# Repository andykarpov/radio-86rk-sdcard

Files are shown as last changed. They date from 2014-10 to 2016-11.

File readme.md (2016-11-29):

# Адаптер SD-CARD для Радио-86РК_SRAM

Данный проект является развитием проекта адаптера SD-CARD  от **Vinxru** 

## Изменения в схеме и печатной плате
- Добавлен LDO регулятор LM1117 3v3
- Вместо резистивных делителей используется буфер HEF4050BT
- добавлен 26-контактный IDC разъем под кабель для сопряжения модуля с Радио-86РК_SRAM
- Добавлен 6-контактный разъем для программатора
- Вместо Atmega8L используется МК Atmega328P

Плата разработана в CAD Eagle 7.0 и выполнена в форм-факторе 5x5 см, что дает возможность заказать ее производство у китайцев. Пробная первая партия была заказана у [http://www.dfrobot.com](http://www.dfrobot.com).

Gerber-файлы для производства платы проходят валидацию по стандартам pcb-сервиса от dfrobot.com.

## Фото готового устройства

Фото

## BOM-list

Микросхемы:

- U1 - Atmega8L(A) (или Atmega328P, или аналогичный МК)

- U2 - HEF4050BT (или другого производителя, 4050 в SMD-корпусе)

- IC1 - LM1117-3.3V

Разъемы:

- CONN1 - 4UCon 19646 или аналогичный ([pdf](http://www.4uconnector.com/online/object/4udrawing/19608.pdf), [Sparkfun](https://www.sparkfun.com/products/12769), [noname разъем на ebay](http://www.ebay.com/itm/5-Pcs-SD-Memory-Card-Sockets-Connectors-Replacements-29-x-28-5-x-2-5mm-/291005194440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))

- CONN2 - угловой 2x13-контактный IDC-разъем (шаг 2.54мм)

- CONN3 - вертикальный 2x3-контактный pin header (шаг 2.54мм)

Резисторы:

- R1 - 470 Ом, корпус 1206

Конденсаторы:

- C1, C2 - 10 мкФ, танталовые полярные, корпус 1206

- C3, C4 - 0.1 мкФ, керамические, корпус 1206

Светодиод:

- LED1 - цвет свечения какой нравится, корпус 1206

## Адаптация исходного кода

Автор оригинальной разработки подготовил файлы boot.rk, sdbios.rk и shell.rk для Радио-86РК (меняются, как минимум, адреса портов).

Прошивка микроконтроллера Atmega8L остается без изменений, можно спокойно заливать авторскую.

Если же проект собирается на базе Atmega328P, то за основу можно взять модифицированную по этот камень прошивку из данного репозитария, в директории *firmware/src/atmega328p*. Вся соль не только в изменившихся адресах портов этого камня, а также в смещении переменной rom, которая в оригинальной конфигурации сидела по адресу 0100h, а теперь сидит по адресу 0200h. 

Также оказалось, что коммандер **shell.rk** не совсем корректно работает с *адаптером PS/2 клавиатуры* и моей кривой клавиатурой с неполной поддержкой ScanCode Set 3, при вызове функции биоса **getch()** возвращает странные значения для кнопок курсора. Соответственно, пришлось придумать альтернативное решение управления курсором, а именно: клавиши **Q,A,O,P**. Модифицированная версия shell.rk расположена в директории *firmware/src/shell_rk/*.

### Fuse bits для МК

На сайте [http://www.engbedded.com/fusecalc/](http://www.engbedded.com/fusecalc/) можно посчитать fuse bits для Вашего МК. 
Необходимо выбрать 

- Internal RC OSC 8MHz, 
- убрать галочку Divide clock by 8 internally

Все остальное можно не трогать или по желанию (например параметры brown out detection).

## Полезные ссылки
- Обсуждение проекта на zx-pk.ru: [http://zx-pk.ru/showthread.php?t=24092](http://zx-pk.ru/showthread.php?t=24092)

- Тема в барахолке на zx-pk.ru: [http://zx-pk.ru/market/viewtopic.php?f=7&t=2567&p=24381](http://zx-pk.ru/market/viewtopic.php?f=7&t=2567&p=24381)

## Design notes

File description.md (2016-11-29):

# Описание работы проекта 86RKSD от автора - Алексея Морозова (по материалам статей в vk.com)

Этот проект очень давно начат и много раз забрасывался. И я возвращаюсь очередной раз. Мы будем подключать флешку к компьютеру Радио 86РК, а точнее подключать к компьютеру микроконтроллер ATMega8 к которому подключена флешка.

### Зачем микроконтроллер? 

Почему бы просто карту памяти не подключить? А вот зачем:

Где то надо хранить программу, которая будет работать с картой памяти. Программа прошитая в ПЗУ компьютера умеет загружать программы только с магнитофона или ПЗУ подключенного к параллельному порту.

Микроконтроллер будет эмулировать внешнее ПЗУ. После включения компьютера, микроконтроллер читает с карты памяти файл и притворяется ПЗУ содержащим эти данные. Компьютер копирует эти данные в память и запускает.

Это только первый этап работы. Дальше пользователь должен увидеть список файлов на экране и иметь возможность как минимум запустить нужный файл. Это уже не эмуляция ПЗУ, это весьма сложная программа, которую раньше называли - дисковая операционная система.

Эта система заняла бы половину памяти компьютера, это бы не позволило запустить большинство программ. И система бы работала бы очень медленно. И сбой компьютера мог бы привести к уничтожению данных на флешке.

Поэтому я решил разместить операционную систему в микроконтроллере. Это быстрее, надежнее и это экономит ресурсы компьютера.

У микроконтроллера **ATMega8** всего **1 Кб ОЗУ** и **8 Кб ПЗУ**. Мне пришлось сильно напрячь голову, что бы написать ОС способную работать на таких скромных объемах.

### Плата

Обобщая написанное. Плата подключается к параллельному порту компьютера. На плате находится микроконтроллер, внутри которого находится эмулятор ПЗУ. Загрузить программу из ПЗУ можно с помощью стандартной директивы **R0,100 G**. Загруженная программа уже будет работать с операционной системой внутри микроконтроллера.

Помимо микроконтроллера и слота для карты, на плате еще несколько деталей для согласования карты с компьютером. Компьютер работает с напряжением **5 Вольт**, а карта памяти **3.3 Вольта**.

### Программа эмуляции ПЗУ

Писать пришлось на ассемблере, так как программа на **Си** не успевала. Компилятор **CodeVision AVR** находится в режиме оптимизации размера в ущерб скорости. Если выключить этот режим, то программа не помещается в микроконтроллер.

Ничего сложного, но заставить все это работать вместе оказалось не так просто (не так быстро). Начинаем писать:

```
// Шина данных на выход

#define DATA_OUT DDRC = 0b00111111, DDRB = 0b11101101;

// Шина данных на вход

#define DATA_IN DDRD = 0x00000000, DDRB = 0b00101101;

void main() {

  DDRD = 0;    // Шина адреса на вход

  DATA_OUT // Шина данных на выход. а так же настраиваем остальные выводы.

  PORTB = 0b00010000; // Подтягивающий резистор на MISO

  // Пауза, пока не стабилизируется питание

  delay_ms(100);

  // Запуск файловой системы

  if(fs_init()) error();

  // Открываем файл boot/boot.rk

  strcpyf(buf, "boot/boot.rk");

  if(fs_open()) error();

  // Он должен быть не больше 128 байт

  if(fs_getfilesize()) error();

  if(fs_tmp > 128) error();

  // Чиатем его в массив rom

  if(fs_read0(rom, (WORD)fs_tmp)) error();

    // Эмуляция ПЗУ

  while(1) {

#asm

        IN   R30, PIND          ; Получаем адрес от компьютера в R30

        LDI  R31, 1               ; Массив rom находится по адресу 0x100. Записываем в R31 единицу.

        LD   R30, Z               ; Читаем в R30 из адреса R31:R30

        OUT  PORTC, R30         ; Отдаем младшие 6 бит компьютеру

        IN   R31, PORTB         ; Отдаем старшие 2 бита компьютеру

        ANDI R31, 0x3F

        ANDI R30, 0xC0

        OR   R31, R30

        OUT  PORTB, R31

#endasm

  }

}
```

###Переключение из режима эмуляции ПЗУ в режим общения с микроконтроллером

Следующим этапом будет переключение из режима эмуляции ПЗУ в режим полноценного общения с микроконтроллером.

Для выхода из этого режима надо последовательно прочитать ячейки ПЗУ: **19, 23, 87**. После этого на шине данных должен появится байт **40h** (константа **ERR_START**).

1). ПРОЧИТАТЬ ДАННЫЕ ПО **АДРЕСУ 19**

2). ПРОЧИТАТЬ ДАННЫЕ ПО **АДРЕСУ 23**

3). ПРОЧИТАТЬ ДАННЫЕ ПО **АДРЕСУ 87**

Далее микроконтроллер будет отдавать данные по тактовому импульсу. В качестве тактового импульса используется линия адреса **A0**. Что бы прочитать или передать очередной байт, надо обратится по адресам **86, 87**. Чтение любого другого адреса вызовет перезагрузку контроллера и возврат в режим **эмуляции ПЗУ**.

После **ERR_START (40h)**, микроконтроллер передает байт **ERR_OK_WAIT (41h)**. И будет передавать его, пока проверяет наличие карты памяти и инициализирует файловую систему. Если инициализация прошла без ошибок, микроконтроллер передает байт **ERR_OK_DISK (42h)**.

4). ЕСЛИ ПРОЧИТАННЫЕ ДАННЫЕ **40h**, РАБОТАЕМ ДАЛЬШЕ

5). ПРОЧИТАТЬ ДАННЫЕ ПО АДРЕСУ **86**

6). ПРОЧИТАТЬ ДАННЫЕ ПО АДРЕСУ **87**

7). ЕСЛИ ПРОЧИТАННЫЕ ДАННЫЕ **41h**, ПЕРЕЙТИ НА ПУНКТ 5

8). ЕСЛИ ПРОЧИТАННЫЕ ДАННЫЕ **42h**, РАБОТАЕМ ДАЛЬШЕ

Дальше, компьютер должен переключить шину данных на передачу, а микроконтроллер на прием. Если компьютер и контроллер одновременно переключатся в режим передачи, произойдет короткое замыкание. Что бы такого не было, переключение в режим передачи происходит в два такта.

Сначала компьютер дергает тактовый сигнал. Микроконтроллер переключается в режим приема. В этот момент времени на шине нет передающего устройства и соответственно в этот такт данные не передаются. Потом компьютер переключается в режим передачи и выставляет передаваемые данные на шину. И только после этого дергает тактовый сигнал и микроконтроллер читает данные.

9). ПРОЧИТАТЬ ДАННЫЕ ПО АДРЕСУ **86**

10). ПРОЧИТАТЬ ДАННЫЕ ПО АДРЕСУ **87**

11). ПЕРЕКЛЮЧИТЬ КОМПЬЮТЕР В РЕЖИМ ПЕРЕДАЧИ

Сейчас мы передаем все данные для команды. Код команды и её аргументы. После передачи каждого байта мы дергаем тактовую линию.

12). ПЕРЕДАТЬ БАЙТ **0** (это команда загрузки файла **sdbios.rk**)

13). ПРОЧИТАТЬ ДАННЫЕ ПО АДРЕСУ **86**

14). ПРОЧИТАТЬ ДАННЫЕ ПО АДРЕСУ **87**

После передачи команды надо опять поменять направление передачи. Микроконтроллер сохраняет данные сразу же по перепаду тактового импульса. Микроконтроллер быстрее компьютера в 20 раз. Поэтому мы можем сразу же после передачи байта переключить компьютер в режим приема. И дернуть тактовый импульс, микроконтроллер переключит шину в режим передачи и выставит передаваемый байт.

15). ПЕРЕКЛЮЧИТЬ КОМПЬЮТЕР В РЕЖИМ ПРИЕМА

16). ПРОЧИТАТЬ ДАННЫЕ ПО АДРЕСУ **86**

17). ПРОЧИТАТЬ ДАННЫЕ ПО АДРЕСУ **87**

18). ЕСЛИ ПРОЧИТАННЫЕ ДАННЫЕ **41h**, ПЕРЕЙТИ НА ПУНКТ 16

19). ЕСЛИ ПРОЧИТАННЫЕ ДАННЫЕ **47h**, РАБОТАЕМ ДАЛЬШЕ

20). ПРИНИМАЕМ И ЗАПУСКАЕМ ФАЙЛ

**Код 47** значит, что файл найден и загружен. Можно начать его прием.

Теперь надо заставить это работать.

Написал программу. Проблема была только с тем, что при переключении режима порта (прием/передача), все линии порта сбрасываются в ноль. Пришлось для тактового сигнала выбрать значения 0 и 1. И волшебная комбинация перехода стала **84h, 80h, 0h**.

Работает :)

###SDBIOS

Теперь надо адаптировать SDBIOS. Это маленькая программа, которая загружается в память во вторую очередь и содержит все функции для работы с флешкой.

Программам использующим флешку не надо самим лезть в порты и соблюдать протокол передачи. Надо просто вызвать функцию этого **SDBIOS**. Помимо упрощения жизни, этот SDBIOS позволит (если потребуется) использовать вместо флешки любой контроллер и любой накопитель.

У используемого микроконтроллера всего 1 Кб оперативной памяти. Поэтому файл в компьютер перегружается блоками по 512 байт.

20). ПРИНИМАЕМ И ЗАПУСКАЕМ ФАЙЛ в действительности достаточно сложный. Я не буду писать ПРОЧИТАТЬ ДАННЫЕ ПО АДРЕСУ 1, 0, что бы сократить текст

21). ПОЛУЧАЕМ АДРЕС ЗАГРУЗКИ ФАЙЛА (2 байта)

22). ЖДЕМ ПОКА КОНТРОЛЛЕР ПЕРЕДАЕТ ERR_WAIT

23). ЕСЛИ МЫ ПРИНЯЛИ **ERR_OK_READ**, ТО ФАЙЛ ПОЛНОСТЬЮ ЗАГРУЖЕН БЕЗ ОШИБОК И МЫ ЕГО ЗАПУСКАЕМ

24). ЕСЛИ МЫ ПРИНЯЛИ НЕ 0, ВЫХОДИМ С ОШИБКОЙ.

25). ПОЛУЧАЕМ ДЛИНУ БЛОКА (2 байта)

26). ПОЛУЧАЕМ БЛОК ДАННЫХ И ЗАПИСЫВАЕМ ЕГО В ПАМЯТЬ

27). ПЕРЕХОДИМ НА 22

####Запуск файла

Но никому с этим парится не придется. Для запуска любого файла надо лишь занести его имя в регистр HL и вызвать подпрограмму Exec.

```
MVI A, 0 ; Код команды

LXI H, FILENAME

CALL SDBIOS
```

####Изменения

поменял используемые выводы микроконтроллера, что позволило упростить программу, поднять скорость работы и надежность.

До этого шина данных компьютера была разбита на два порта микроконтроллера и при записи приходилось выполнять медленную программу

````
PORTC = d;

PORTD = (PORTD & 0x3F) | (d & 0xC0);
````

Теперь же медленный способ используется для шины адреса. А шина адреса используется только на чтение и только эмулятором ПЗУ, который нужен только для начальной загрузки. После загрузки общение происходит исключительно через шину данных и она теперь не тормозит.

###Резюме

Плата контроллер подойдет к любому **Радио 86РК**. А так же другим компьютерам с **ВВ55**-ым портом и поддерживающим загрузку с ПЗУ подключенному к этому порту. Например: Ориону, Корвету.

Только для разных компьютеров будет разных набор файлов на флешке. Для различных Радио 86РК они будут отличаться адресами загрузки и портов.

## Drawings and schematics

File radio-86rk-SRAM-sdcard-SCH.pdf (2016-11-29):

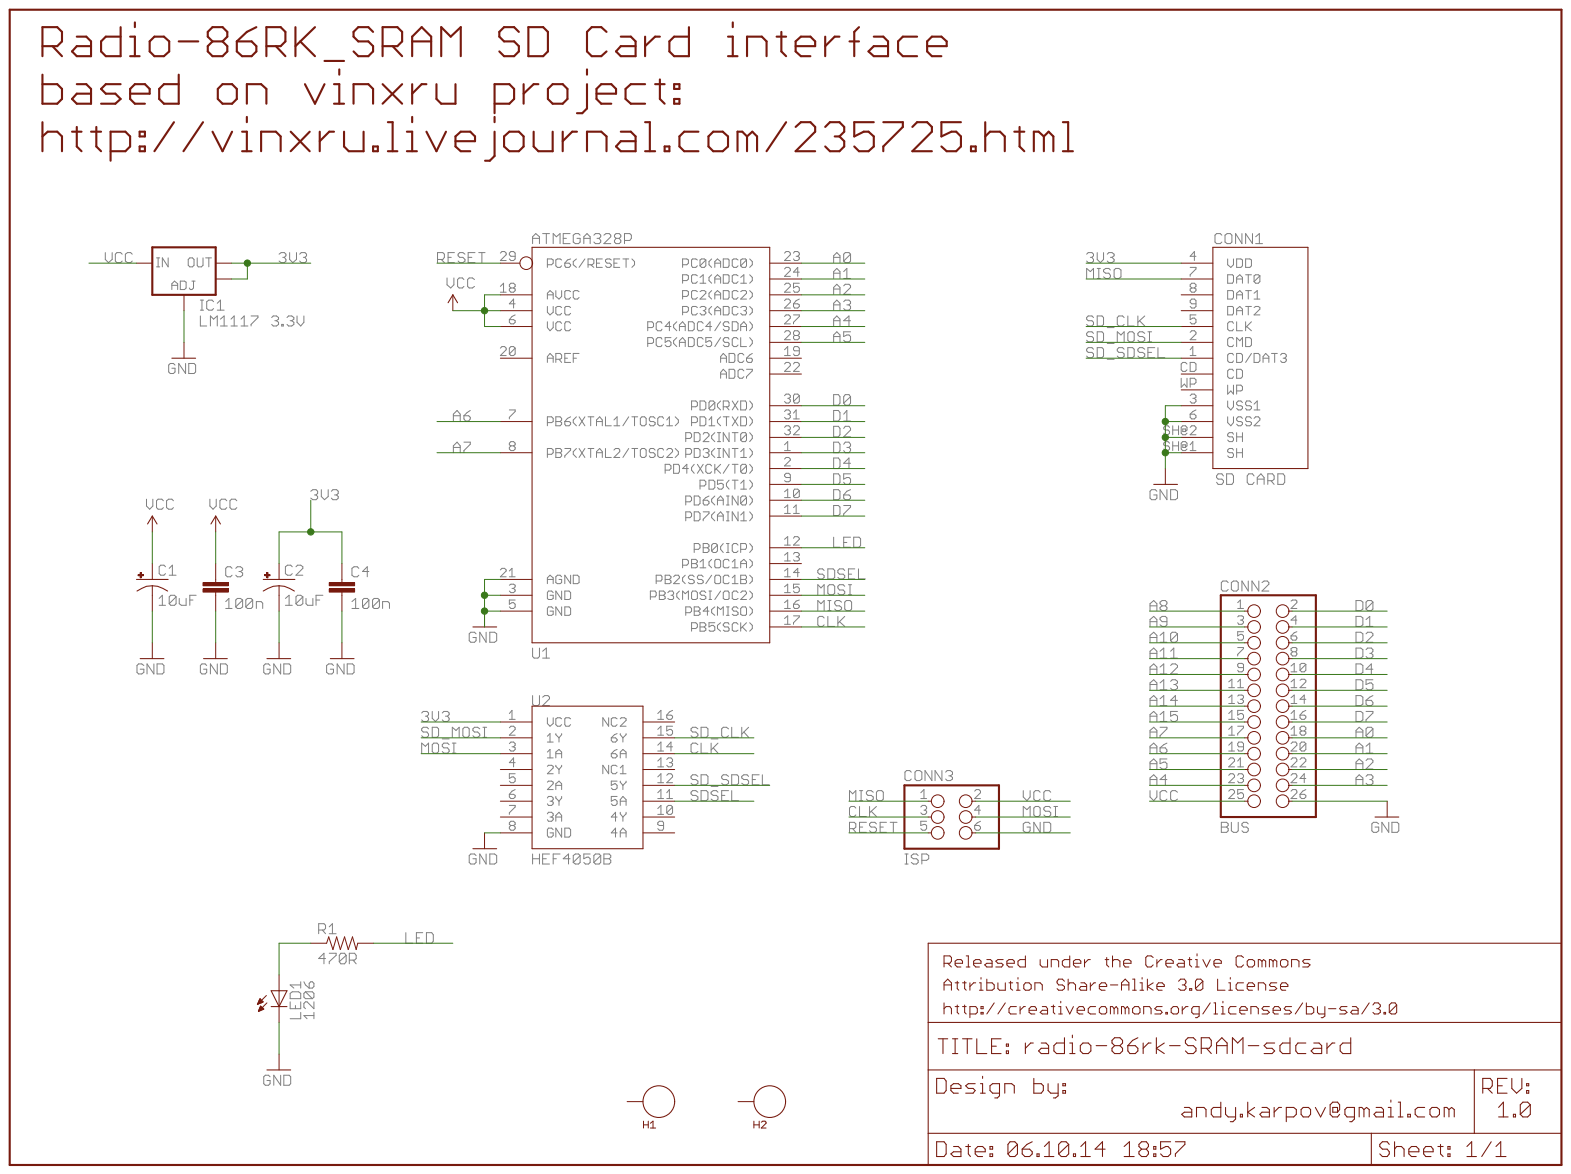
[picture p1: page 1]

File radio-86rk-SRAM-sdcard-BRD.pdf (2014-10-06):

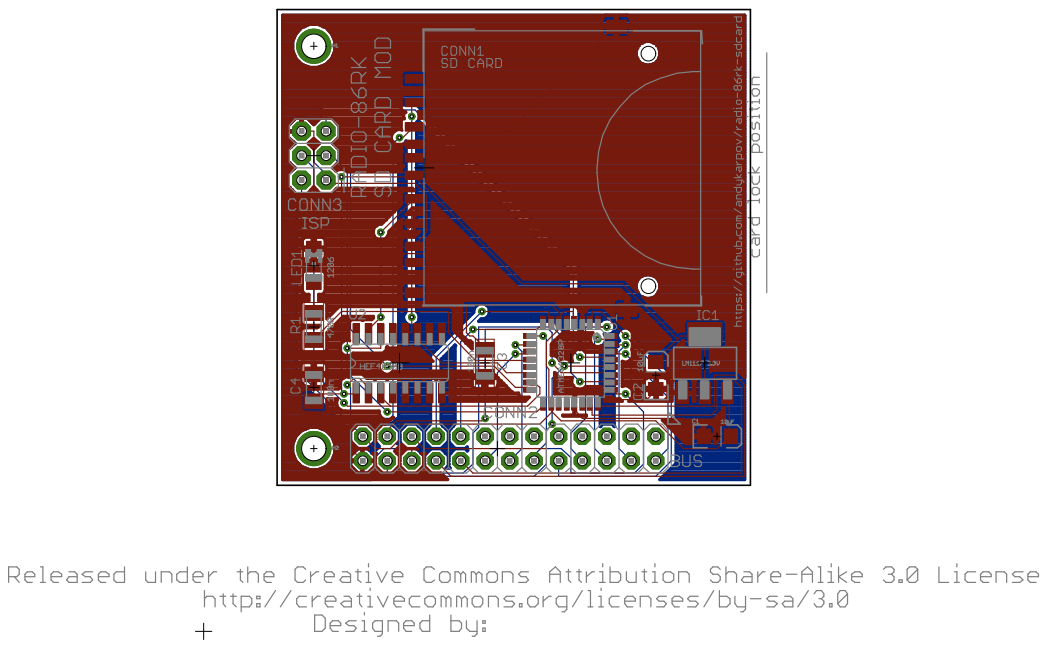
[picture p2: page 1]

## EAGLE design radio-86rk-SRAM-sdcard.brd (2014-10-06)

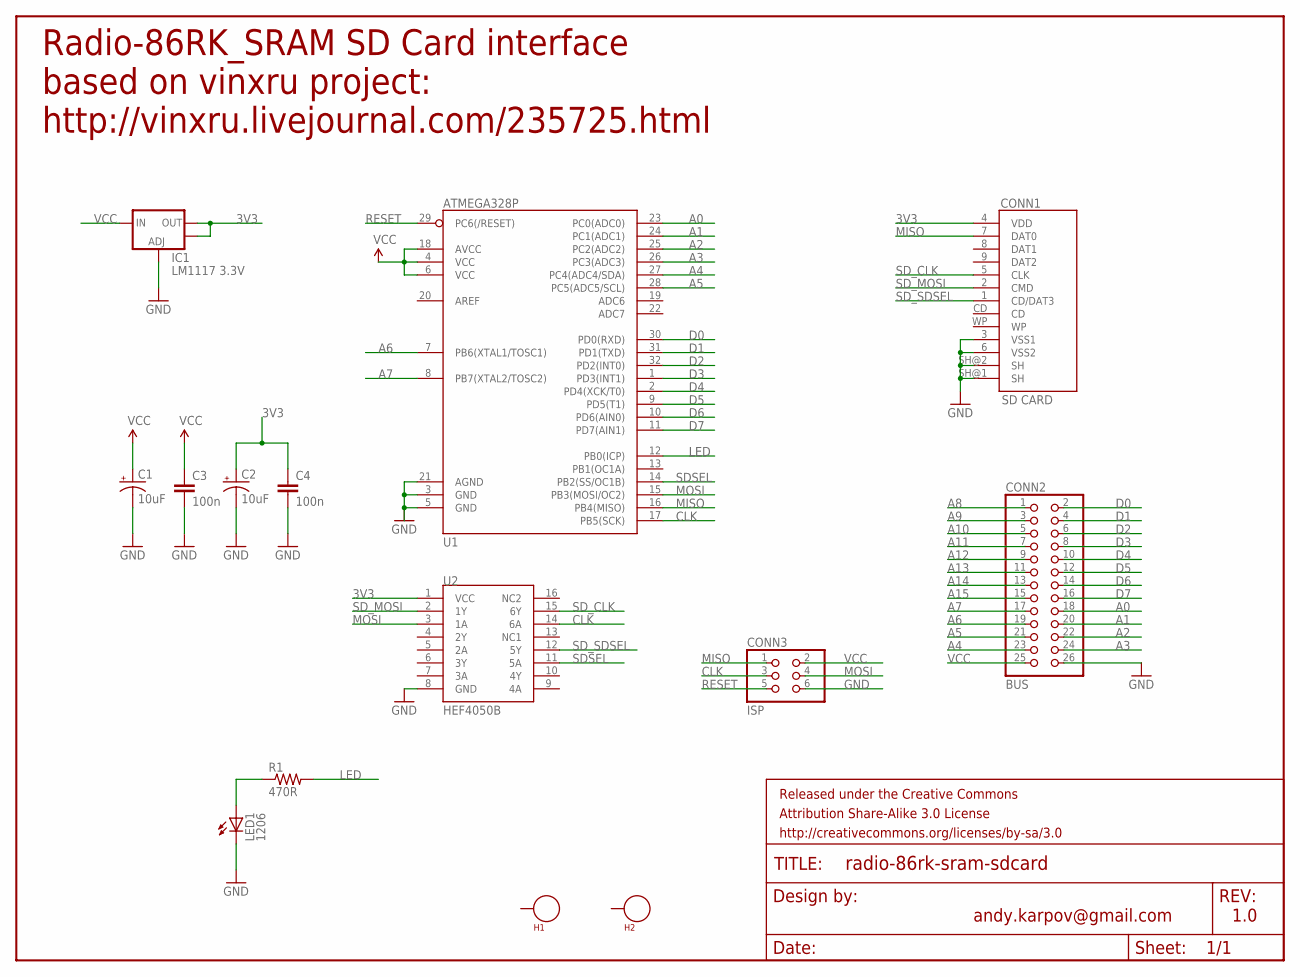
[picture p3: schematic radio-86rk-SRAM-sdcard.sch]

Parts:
C1, C2: 10uF; EIA3216
C3, C4: 100n; 1206
CONN1: SD CARD; SDCARD_4UCONN
CONN2: BUS; 2X13
CONN3: ISP; 2X03
FRAME1: FRAME-LETTER; CREATIVE_COMMONS
H1, H2: SEW_HOLE; SIMPLE_HOLE
IC1: LM1117 3.3V; SOT223
LED1: 1206; CHIPLED_1206
R1: 470R; 1206
U1: ATMEGA328P; TQFP32-08
U2: HEF4050B; SO16

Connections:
3V3: C2.A (+), C4.1, CONN1.4 (VDD), IC1.2 (OUT), IC1.4 (OUT), U2.1 (VCC)
A0: CONN2.18, U1.23 (PC0(ADC0))
A1: CONN2.20, U1.24 (PC1(ADC1))
A2: CONN2.22, U1.25 (PC2(ADC2))
A3: CONN2.24, U1.26 (PC3(ADC3))
A4: CONN2.23, U1.27 (PC4(ADC4/SDA))
A5: CONN2.21, U1.28 (PC5(ADC5/SCL))
A6: CONN2.19, U1.7 (PB6(XTAL1/TOSC1))
A7: CONN2.17, U1.8 (PB7(XTAL2/TOSC2))
A8: CONN2.1
A9: CONN2.3
A10: CONN2.5
A11: CONN2.7
A12: CONN2.9
A13: CONN2.11
A14: CONN2.13
A15: CONN2.15
CLK: CONN3.3, U1.17 (PB5(SCK)), U2.14 (6A)
D0: CONN2.2, U1.30 (PD0(RXD))
D1: CONN2.4, U1.31 (PD1(TXD))
D2: CONN2.6, U1.32 (PD2(INT0))
D3: CONN2.8, U1.1 (PD3(INT1))
D4: CONN2.10, U1.2 (PD4(XCK/T0))
D5: CONN2.12, U1.9 (PD5(T1))
D6: CONN2.14, U1.10 (PD6(AIN0))
D7: CONN2.16, U1.11 (PD7(AIN1))
GND: C1.C (-), C2.C (-), C3.2, C4.2, CONN1.3 (VSS1), CONN1.6 (VSS2), CONN1.SH@1 (SH), CONN1.SH@2 (SH), CONN2.26, CONN3.6, IC1.1 (ADJ), LED1.C, U1.3 (GND), U1.5 (GND), U1.21 (AGND), U2.8 (GND)
LED: R1.2, U1.12 (PB0(ICP))
MISO: CONN1.7 (DAT0), CONN3.1, U1.16 (PB4(MISO))
MOSI: CONN3.4, U1.15 (PB3(MOSI/OC2)), U2.3 (1A)
unnamed: LED1.A, R1.1
RESET: CONN3.5, U1.29 (PC6(/RESET))
SDSEL: U1.14 (PB2(SS/OC1B)), U2.11 (5A)
SD_CLK: CONN1.5 (CLK), U2.15 (6Y)
SD_MOSI: CONN1.2 (CMD), U2.2 (1Y)
SD_SDSEL: CONN1.1 (CD/DAT3), U2.12 (5Y)
VCC: C1.A (+), C3.1, CONN2.25, CONN3.2, IC1.3 (IN), U1.4 (VCC), U1.6 (VCC), U1.18 (AVCC)

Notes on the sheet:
Radio-86RK_SRAM SD Card interface based on vinxru project: http://vinxru.livejournal.com/235725.html
andy.karpov@gmail.com
1.0

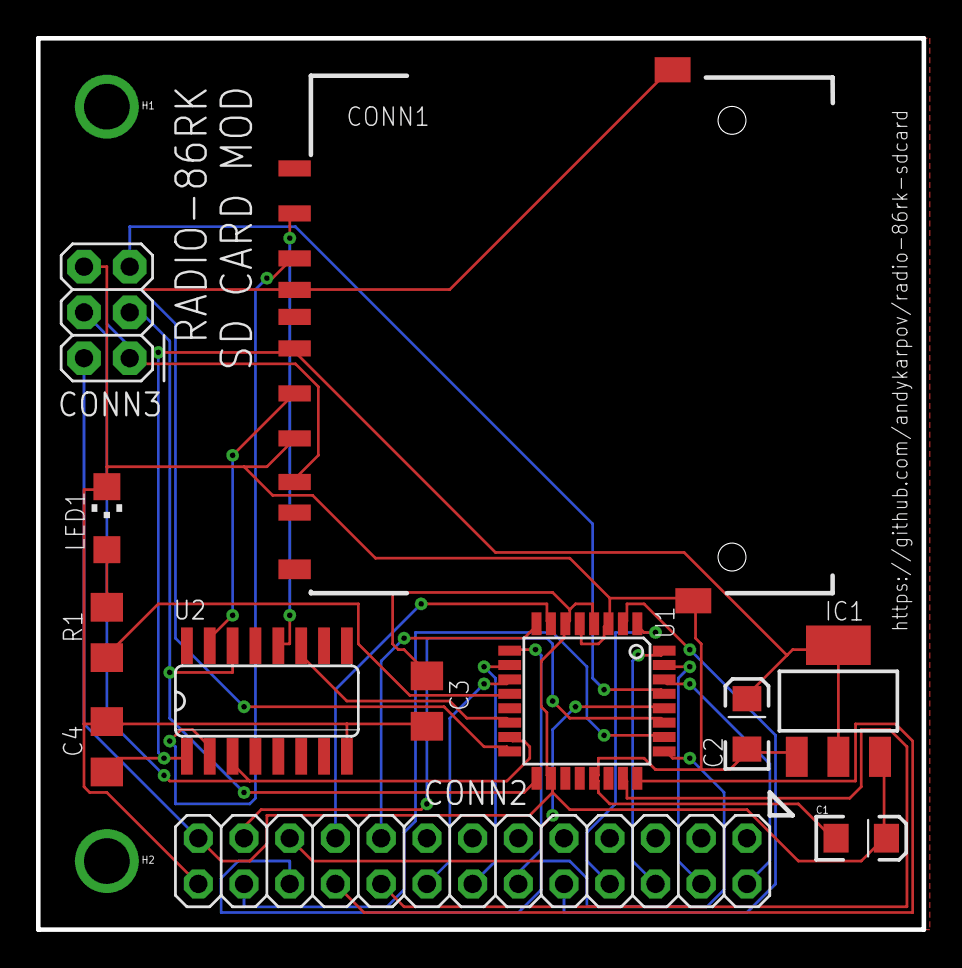
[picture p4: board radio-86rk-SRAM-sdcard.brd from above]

Board: 2 copper layers, 49.2 x 49.5 mm, 15 parts (0 on the bottom side), 29 nets.

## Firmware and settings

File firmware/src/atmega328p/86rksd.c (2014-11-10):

// SD Controller for Computer "Radio 86RK" / "Apogee BK01"
// (c) 10-05-2014 vinxru (aleksey.f.morozov@gmail.com)

//#include <stdafx.h>

#define F_CPU 8000000UL        //freq 8 MHz

#include "common.h"
#include <string.h>
#include "sd.h"
#include "fs.h"
#include "proto.h"

#ifndef X86_DEBUG
#include <delay.h>
#endif

#define O_OPEN   0
#define O_CREATE 1
#define O_MKDIR  2
#define O_DELETE 100
#define O_SWAP   101

#define ERR_START       0x40
#define ERR_WAIT        0x41
#define ERR_OK_DISK         0x42
#define ERR_OK_CMD          0x43
#define ERR_OK_READ         0x44
#define ERR_OK_ENTRY        0x45
#define ERR_OK_WRITE        0x46
#define ERR_OK_RKS          0x47
#define ERR_READ_BLOCK      0x4F

BYTE buf[512];
BYTE rom[128];

/*******************************************************************************
* Для удобства                                                                 *
*******************************************************************************/

void recvBin(BYTE* d, WORD l) {
  for(; l; --l) {
    *d++ = wrecv();
  }  
}

void recvString() {
  BYTE c;
  BYTE* p = buf;       
  do {
    c = wrecv();
    if(p != buf + FS_MAXFILE) *p++ = c; else lastError = ERR_RECV_STRING;
  } while(c);
}

void sendBin(BYTE* p, WORD l) {
  for(; l; l--)
    send(*p++);
}

void sendBinf(flash BYTE* d, BYTE l) {
  for(; l; --l)
    send(*d++);
}

/*******************************************************************************
* Отправка всех блоков файла                                                   *
*******************************************************************************/

WORD readLength;

void readInt(char rks) { 
  WORD readedLength, lengthFromFile;        
  BYTE tmp;
  BYTE* wptr;

  while(readLength) { 
    // Расчет длины блока (выравниваем чтение на сектор)
    if(fs_tell()) return;
    readedLength = 512 - (fs_tmp % 512);
    if(readedLength > readLength) readedLength = readLength;

    // Уменьшаем счетчик
    readLength -= readedLength;

    // Читаем блок
    if(fs_read0(buf, readedLength)) return;

    // Заголовок RKS файла
    wptr = buf;
    if(rks) { // Если rks=1, перед вызовом надо проверить, что бы readLength>4 и fs_file.ptr=0, иначе может быть злостный сбой
      rks = 0;
      
      // У апогея числа перепутаны
      tmp=buf[0], buf[0]=buf[1]; buf[1]=tmp;
      tmp=buf[2], buf[2]=buf[3]; buf[3]=tmp;

      // Посылаем адрес загрузки
      send(ERR_OK_RKS);
      sendBin(buf, 2);    
      send(ERR_WAIT);

      // Корректируем указатели
      wptr += 4;
      readedLength -= 4;

      // Длина из файла
      lengthFromFile = *(WORD*)(buf+2) - *(WORD*)(buf) + 1;

      // Корректируем длину  
      if(readedLength > lengthFromFile) {
        readedLength = lengthFromFile;
      } else {          
        lengthFromFile -= readedLength;
        if(readLength > lengthFromFile) lengthFromFile = readedLength;
      }
    }  

    // Отправляем блок
    send(ERR_READ_BLOCK);    
    sendBin((BYTE*)&readedLength, 2);
    sendBin(wptr, readedLength);
    send(ERR_WAIT);
  }

  // Если все ОК
  if(!lastError) lastError = ERR_OK_READ;
}

/*******************************************************************************
* Версия команд контроллера                                                    *
*******************************************************************************/

void cmd_ver() {
  sendStart(1);
    
  // Версия + Производитель
  sendBinf("V1.0 10-05-2014 ", 16);
              //0123456789ABCDEF
}

/*******************************************************************************
* BOOT / EXEC                                                                  *
*******************************************************************************/

void cmd_boot_exec() {
  // Файл по умолчанию
  if(buf[0]==0) strcpyf(buf, "boot/sdbios.rk");      

  // Открываем файл
  if(fs_open()) return;
  
  // Максимальный размер файла
  readLength = 0xFFFF;  
  if(fs_getfilesize()) return;
  if(readLength > fs_tmp) readLength = (WORD)fs_tmp;

  // Файлы RK должны быть длиной >4 байт. Мы заносим в readLength = 0 и программа
  // получает ERR_OK. Но так как она ждем ERR_OK_RKS, это будет ошибкой 
  if(readLength < 4) readLength = 0;

  readInt(/*rks*/1);  
}

void cmd_boot() { 
  sendStart(ERR_WAIT);
  buf[0] = 0;
  cmd_boot_exec();  
}

void cmd_exec() {     
  // Прием имени файла
  recvString();

  // Режим передачи и подтверждение
  sendStart(ERR_WAIT);
  if(lastError) return; // Переполнение строки
  
  cmd_boot_exec();    
}

/*******************************************************************************
* Начать/продолжить посик файлов в папке                                       *
*******************************************************************************/

typedef struct {
    char    fname[11];    // File name
    BYTE    fattrib;    // Attribute
    DWORD   fsize;        // File size
    union {
      struct {
        WORD    ftime;        // Last modified time
        WORD    fdate;        // Last modified date 
      };
      DWORD ftimedate;
    };
} FILINFO2;

void cmd_find() {
  WORD n;
  FILINFO2 info;              
  
  // Принимаем путь
  recvString();

  // Принимаем макс кол-во элементов
  recvBin((BYTE*)&n, 2);

  // Режим передачи и подтверждение
  sendStart(ERR_WAIT);
  if(lastError) return;

  // Открываем папку
  if(buf[0] != ':') {
    if(fs_opendir()) return;
  }

  for(; n; --n) {
    /* Читаем очереной описатель */
    if(fs_readdir()) return;

    /* Конец */
    if(FS_DIRENTRY[0] == 0) {
      lastError = ERR_OK_CMD;
      return;
    }

    /* Сжимаем ответ для компьютера */
    memcpy(info.fname, FS_DIRENTRY+DIR_Name, 12);
    memcpy(&info.fsize, FS_DIRENTRY+DIR_FileSize, 4);
    memcpy(&info.ftimedate, FS_DIRENTRY+DIR_WrtTime, 4);
    //memcpy(memcpy(memcpy(info.fname, FS_DIRENTRY+DIR_Name, 12, FS_DIRENTRY+DIR_FileSize, 4), FS_DIRENTRY+DIR_WrtTime, 4);

    /* Отправляем */
    send(ERR_OK_ENTRY);
    sendBin((BYTE*)&info, sizeof(info));
    send(ERR_WAIT);
  }

  /* Ограничение по размеру */  
  lastError = ERR_MAX_FILES; /*! Надо опеределать, что бы не было ложных ошибок */
}

/*******************************************************************************
* Открыть/создать файл/папку                                                   *
*******************************************************************************/

void cmd_open() {
  BYTE mode;
 
  /* Принимаем режим */
  mode = wrecv();    

  // Принимаем имя файла
  recvString();

  // Режим передачи и подтверждение
  sendStart(ERR_WAIT);

  // Открываем/создаем файл/папку
  if(mode == O_SWAP) {
    fs_swap();
  } else
  if(mode == O_DELETE) {
    fs_delete();
  } else
  if(mode == O_OPEN) {
    fs_open();
  } else 
  if(mode < 3) {
    fs_open0(mode);
  } else {
    lastError = ERR_INVALID_COMMAND;
  }

  // Ок
  if(!lastError) lastError = ERR_OK_CMD;
}

/*******************************************************************************
* Переместить файл/папку                                                       *
*******************************************************************************/

void cmd_move() {
  recvString();
  sendStart(ERR_WAIT);
  fs_openany();
  sendStart(ERR_OK_WRITE);
  recvStart();
  recvString();
  sendStart(ERR_WAIT);
  if(!lastError) fs_move0();
  if(!lastError) lastError = ERR_OK_CMD;
}

/*******************************************************************************
* Установить/прочитать указатель чтения                                        *
*******************************************************************************/

void cmd_lseek() {
  BYTE mode;
  DWORD off;

  // Принимаем режим и смещение
  mode = wrecv();    
  recvBin((BYTE*)&off, 4);    

  // Режим передачи и подтверждение
  sendStart(ERR_WAIT);

  // Размер файла
  if(mode==100) {
    if(fs_getfilesize()) return;
  }

  // Размер диска  
  else if(mode==101) {
    if(fs_gettotal()) return;
  }
 
  // Свободное место на диске
  else if(mode==102) {
    if(fs_getfree()) return;
  }

  else {
    /* Устаналиваем смещение. fs_tmp сохраняется */
    if(fs_lseek(off, mode)) return;
  }

  // Передаем результат
  send(ERR_OK_CMD);
  sendBin((BYTE*)&fs_tmp, 4);  
  lastError = 0; // На всякий случай, результат уже передан
}

/*******************************************************************************
* Прочитать из файла                                                           *
*******************************************************************************/

void cmd_read() {
  DWORD s;

  // Длина
  recvBin((BYTE*)&readLength, 2);

  // Режим передачи и подтверждение
  sendStart(ERR_WAIT);

  // Ограничиваем длину длиной файла
  if(fs_getfilesize()) return;
  s = fs_tmp; 
  if(fs_tell()) return;
  s -= fs_tmp;
                    
  if(readLength > s)
    readLength = (WORD)s;

  // Отправляем все блоки файла
  readInt(/*rks*/0);
}

/*******************************************************************************
* Записать данные в файл                                                       *
*******************************************************************************/

void cmd_write() {
  // Аргументы
  recvBin((BYTE*)&fs_wtotal, 2); 

  // Ответ
  sendStart(ERR_WAIT);
           
  // Конец файла
  if(fs_wtotal==0) {
    fs_write_eof();
    lastError = ERR_OK_CMD;
    return;
  }
  
  // Запись данных
  do {
    if(fs_write_start()) return;

    // Принимаем от компьюетра блок данных
    send(ERR_OK_WRITE);
    sendBin((BYTE*)&fs_file_wlen, 2);
    recvStart();    
    recvBin(fs_file_wbuf, fs_file_wlen);
    sendStart(ERR_WAIT);

    if(fs_write_end()) return;
  } while(fs_wtotal);

  lastError = ERR_OK_CMD;
}

/*******************************************************************************
* Главная процедура                                                            *
*******************************************************************************/

void error() {
  for(;;) {
    PORTB.0 = 1;
    delay_ms(100);
    PORTB.0 = 0;
    delay_ms(100);
  }
}

void main() {
  BYTE c, d, i;
    
  DATA_OUT            // Шина данных (DDRD)
  DDRC  = 0b00000000; // Шина адреса
  DDRB  = 0b00101101; // Шина адреса, карта и светодиод
  PORTB = 0b00010001; // Подтягивающий резистор на MISO и светодиод  

  // Пауза, пока не стабилизируется питание
  delay_ms(500);

  // Запуск файловой системы
  if(fs_init()) error();
  strcpyf(buf, "boot/boot.rk");
  if(fs_open()) error();
  if(fs_getfilesize()) error();
  if(fs_tmp < 7) error();
  if(fs_tmp > 128) error();
  if(fs_read0(rom, (WORD)fs_tmp)) error();  
                   
  delay_ms(100);
  
  // Гасим светодиод
  PORTB.0 = 0;
  
  while(1) {
    // Эмуляция ПЗУ
#asm
.EQU PIND  = $9
.EQU DDRD  = 0xa
.EQU PORTD = 0xb
.EQU PINC  = $6
.EQU DDRC  = $7
.EQU PORTC = $8
.EQU PINB  = $3
.EQU DDRB  = $4
.EQU PORTB = $5
.EQU ROM   = 2

.macro GET_ADDR
        IN   R30, PINC         ; Младшие 6 бит
        ANDI R30, 0x3F
        IN   R26, PINB         ; Старший бит
        ANDI R26, 0x40
        OR   R30, R26
.endmacro

.macro ROM_EMU
        LD   R30, Z
        OUT  PORTD, R30
        ;NOP
        ;NOP
        ;NOP
        ;NOP
.endmacro

        ; Устаналвиается один раз для ROM_EMU
        PUSH R26
        PUSH R30
        PUSH R31
        LDI  R31, ROM                    

        ; Получаем адрес
        GET_ADDR
        
        ; Эмулируем ПЗУ          
LOOP0:  ROM_EMU
                  
        ; Получаем адрес и если это не 0x44, то переходим в начало
        GET_ADDR
        CPI  R30, 0x44
        BRNE LOOP0
        
        ; Эмулируем ПЗУ (0x44-ый адрес)
        ROM_EMU
                
        ; Получаем адрес и если это все еще 0x44, то ждем.        
        ; Если это не 0x40, то переходим в начало         
LOOP1:  GET_ADDR
        CPI  R30, 0x44
        BREQ LOOP1
        CPI  R30, 0x40
        BRNE LOOP0
            
        ; Эмулируем ПЗУ (0x40-ый адрес)          
        ROM_EMU
        
        ; Получаем адрес и если это все еще 0x40, то ждем.        
        ; Если это не 0, то переходим в начало
LOOP2:  GET_ADDR
        CPI  R30, 0x40
        BREQ LOOP2
        CPI  R30, 0
        BRNE LOOP0                  

        POP R31
        POP R30
        POP R26
#endasm          

    // Зажигаем светодиод
    PORTB.0 = 1;

    // Проверяем наличие карты
    sendStart(ERR_START);
    send(ERR_WAIT);
    if(fs_check()) {
      send(ERR_DISK_ERR);
    } else {
      send(ERR_OK_DISK);
      recvStart();
      c = wrecv();
      
      // Сбрасываем ошибку
      lastError = 0;
    
      // Принимаем аргументы 
      switch(c) {
        case 0:  cmd_boot();         break; 
        case 1:  cmd_ver();          break;
        case 2:  cmd_exec();         break; 
        case 3:  cmd_find();         break;
        case 4:  cmd_open();         break;     
        case 5:  cmd_lseek();        break;     
        case 6:  cmd_read();         break;     
        case 7:  cmd_write();        break; 
        case 8:  cmd_move();         break;
        default: lastError = ERR_INVALID_COMMAND;      
      }
    
      // Вывод ошибки
      if(lastError) sendStart(lastError);
    }

    // Порт рабоатет на выход
    wait();
    DATA_OUT
    
    // Гасим светодиод
    PORTB.0 = 0;
  } 
}

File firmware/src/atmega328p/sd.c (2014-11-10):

/*
It is an open source software to implement SD routines to
small embedded systems. This is a free software and is opened for education,
research and commercial developments under license policy of following trems.

(C) 2013 vinxru (aleksey.f.morozov@gmail.com)

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
Version 0.99 5-05-2013
*/

#include "common.h"
#include <delay.h>
#include "sd.h"
#include "fs.h"

BYTE sd_sdhc; /* Используется SDHC карта */

/**************************************************************************
*  Протокол SPI для ATMega8                                               *
*  Может отличаться для разных МК.                                        *
**************************************************************************/

/* Куда подключена линия CS карты */
#define SD_CS_ENABLE    PORTB &= ~0x04;
#define SD_CS_DISABLE   PORTB |= 0x04;

/* Совместимость с разными версиями CodeVisionAVR */
#ifndef SPI2X
#define SPI2X 0
#endif

#define SPI_INIT      { SPCR = 0x52; SPSR = 0x00; }    
#define SPI_HIGHSPEED { SPCR = 0x50; SPSR |= (1<<SPI2X); delay_ms(1); }

static void spi_transmit(BYTE data) {
  SPDR = data;  
  while(!(SPSR & (1<<SPIF)));
  data = SPDR;
}

static BYTE spi_receive() {        
  SPDR = 0xff;
  while(!(SPSR & (1<<SPIF)));
  return SPDR;  
}

/**************************************************************************
*  Отправка команды                                                       *
**************************************************************************/

/* Используемые каманды SD карты */

#define GO_IDLE_STATE      (0x40 | 0 )
#define SEND_IF_COND       (0x40 | 8 )
#define READ_SINGLE_BLOCK  (0x40 | 17)
#define WRITE_SINGLE_BLOCK (0x40 | 24)
#define SD_SEND_OP_COND    (0x40 | 41)
#define APP_CMD            (0x40 | 55)
#define READ_OCR           (0x40 | 58)

static BYTE sd_sendCommand(BYTE cmd, DWORD arg) {
  BYTE response, retry;
                  
  /* Размещение этого кода тут -4 команды, хотя вроде лишине проверки */
  if(sd_sdhc == 0 && (cmd==READ_SINGLE_BLOCK || cmd==WRITE_SINGLE_BLOCK))  
    arg <<= 9;
  
  /* Выбираем карту */
  SD_CS_ENABLE

  /* Заголовок команды */
  spi_transmit(cmd);
  spi_transmit(((BYTE*)&arg)[3]);
  spi_transmit(((BYTE*)&arg)[2]);
  spi_transmit(((BYTE*)&arg)[1]);
  spi_transmit(((BYTE*)&arg)[0]);

  /* Пару каоманд требуют CRC. Остальные же команды игнорируют его, поэтому упрощаем код */
  spi_transmit(cmd == SEND_IF_COND ? 0x87 : 0x95);

  /* Ждем подтвреждение (256 тактов) */  
  retry = 0;
  while((response = spi_receive()) == 0xFF) 
    if(++retry == 0) break;

  /* Результат команды READ_OCR обрабатываем тут, так как в конце этой функции мы снимем CS и пропускаем 1 байт */
  if(response == 0 && cmd == READ_OCR) {  
    /* 32 бита из которых нас интересует один бит */
    sd_sdhc = spi_receive() & 0x40;
    spi_receive();
    spi_receive();
    spi_receive(); 
  }

  /* отпускаем CS и пауза в 1 байт*/
  SD_CS_DISABLE
  spi_receive(); 

  return response;
}

/**************************************************************************
*  Проверка готовности/наличия карты                                      *
**************************************************************************/

BYTE sd_check() {
  BYTE i = 0;
  do { 
    sd_sendCommand(APP_CMD, 0);
    if(sd_sendCommand(SD_SEND_OP_COND, 0x40000000) == 0) return 0;
  } while(--i);
  return 1;
}

/**************************************************************************
*  Инициализация карты (эта функция вызывается функцией sd_init)          *
**************************************************************************/

static BYTE sd_init_int() {
  BYTE i;

  /* Сбрасываем SDHC флаг */
  sd_sdhc = 0;

  /* Минимум 80 пустых тактов */
  for(i=10; i; --i)
    spi_receive();   

  /* CMD0 Посылаем команду сброса */
  if(sd_sendCommand(GO_IDLE_STATE, 0) != 1) goto abort;

  /* CMD8 Узнаем версию карты */
  i = 0;
  if(sd_sendCommand(SEND_IF_COND, 0x000001AA)) 
    i = 1;

  /* CMD41 Ожидание окончания инициализации */
  if(sd_check()) goto abort;

  /* Только для второй версии карты */
  if(i) {
    /* CMD58 определение SDHC карты. Ответ обрабатывается в функции sd_sendCommand */
    if(sd_sendCommand(READ_OCR, 0) != 0) goto abort;
  }
  
  return 0;    
abort:
  return 1;
}                            

/**************************************************************************
*  Инициализация карты                                                    *
**************************************************************************/

BYTE sd_init() {  
  BYTE tries;

  /* Освобождаем CS на всякий случай */
  SD_CS_DISABLE

  /* Включаем SPI */
  SPI_INIT

  /* Делаем несколько попыток инициализации */
  tries = 10;  
  while(sd_init_int()) 
    if(--tries == 0) {
      lastError = ERR_DISK_ERR;
      return 1;       
    }
          
  /* Вклчюаем максимальную скорость */
  SPI_HIGHSPEED     
  
  return 0;
}

/**************************************************************************
*  Ожидание определенного байта на шине                                   *
**************************************************************************/

static BYTE sd_waitBus(BYTE byte) {
  WORD retry = 0;
  do {
    if(spi_receive() == byte) return 0;
  } while(++retry); 
  return 1;
}

/**************************************************************************
*  Чтение произвольного участка сектора                                   *
**************************************************************************/

BYTE sd_read(BYTE* buffer, DWORD sector, WORD offsetInSector, WORD length) {
  BYTE b;
  WORD i;
    
  /* Посылаем команду */
  if(sd_sendCommand(READ_SINGLE_BLOCK, sector)) goto abort;

  /* Сразу же возращаем CS, что бы принять ответ команды */
  SD_CS_ENABLE

  /* Ждем стартовый байт */
  if(sd_waitBus(0xFE)) goto abort;

  /* Принимаем 512 байт */
  for(i=512; i; --i) {
    b = spi_receive();
    if(offsetInSector) { offsetInSector--; continue; }
    if(length == 0) continue;
    length--;
    *buffer++ = b;
  }

  /* CRC игнорируем */
  spi_receive();
  spi_receive();

  /* отпускаем CS и пауза в 1 байт*/
  SD_CS_DISABLE
  spi_receive(); 

  /* Ок */
  return 0;

  /* Ошибка и отпускаем CS.*/
abort:
  SD_CS_DISABLE
  lastError = ERR_DISK_ERR;
  return 1;
}

/**************************************************************************
*  Запись сектора (512 байт)                                              *
**************************************************************************/
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

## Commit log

2014-10-06 added gerbers
    [radio-86rk-SRAM-sdcard.GBL, radio-86rk-SRAM-sdcard.GBO, radio-86rk-SRAM-sdcard.GBP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]
2014-10-08 Добавлены библиотеки кастомных компонентов для Eagle
2014-10-08 Первая итерация перевода исходников прошивки контроллера на рельсы avr-gcc
2014-10-08 Подпрограмма эмуляции ПЗУ вынесена в отдельный файл rom_emu.S и подключена в Makefile
2014-11-10 Изменения под Atmega328p + мелкие фиксы в работе коммандера
2014-11-10 Убрана неработающая песочница по переносу проекта на рельсы avrgcc
2014-11-10 Добавлены полезные ссылки
2014-11-10 Добавлено упоминание про gerbers
2014-11-10 Добавлен hotfix, если от PS/2 контроллера пришел залипший где-то в проводах сигнал нажатия клавиши enter
2014-11-15 Добавлен BOM-лист, мелкие фиксы
2016-11-29 Обновлен readme, добавлены исходники компилятора и архив утраченного проекта vinxru (спасибо cy6)
2016-11-29 Описание работы проекта от автора

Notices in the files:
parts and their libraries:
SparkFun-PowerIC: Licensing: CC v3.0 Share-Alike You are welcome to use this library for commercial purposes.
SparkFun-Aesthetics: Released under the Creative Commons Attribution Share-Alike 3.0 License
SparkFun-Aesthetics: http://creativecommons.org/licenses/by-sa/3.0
